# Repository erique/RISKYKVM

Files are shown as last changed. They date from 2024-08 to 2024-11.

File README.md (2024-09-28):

# RISKYKVM
Amiga adapter targets KVMs, but can be used as USB to DB9 and Amiga Keyabord interface

Project is based on following projects:
- Mist (USB HID parser stack)
- Mouse Driver - sq7bti.
- Simon Inns smallymouse2 mouse quadrature encoding
- Amiga Keyboard handler: https://github.com/gianlucarenzi/stalker
- WCH Example projects for CH32V203

## BOM
- "C1,C2,C3,C4,C5,C6" - 100nF 0603 
- "C9" - 0.1μF 0603
- "D1,D2" - LED 0805
- "F1" - Fuse 1206 500MA
- "J1" - DB9_Plug
- "J2" - Conn_01x02
- "J3" - USB_1
- "J4" - Conn_01x08
- "R1,R3" - aprox 200OHM (based on LED used)
- "R2" - 10K
- "U1" - CH32V203C8T6
- "U2" - LM1117MP-3.3 SOT-89

## Programming
WCH-LINK programmer is needed for initial programming of bootloader (bootloader.hex), then you can program application (RISKYKVM.UPD) using FAT32 formatted USB FLash drive.
To program bootloader or standard version of firmware use MounRiver IDE.

### Programming application firmware with custom bootloader.
1. Short CLK and DIO pins togeter, and power on device. When RDY LED starts to blink few times.
2. Insert USB Flash drive with RISKYKVM.UPD file in root directory.
3. If flashing is sucessful RDY LED will start slowly flashing 10x, if process failes then RDY flash either will be off, or will start flashing quickly 100x.
4. Power off device, remove jumper or disconnect CLK and DIO pins.
5. Device is ready to use.



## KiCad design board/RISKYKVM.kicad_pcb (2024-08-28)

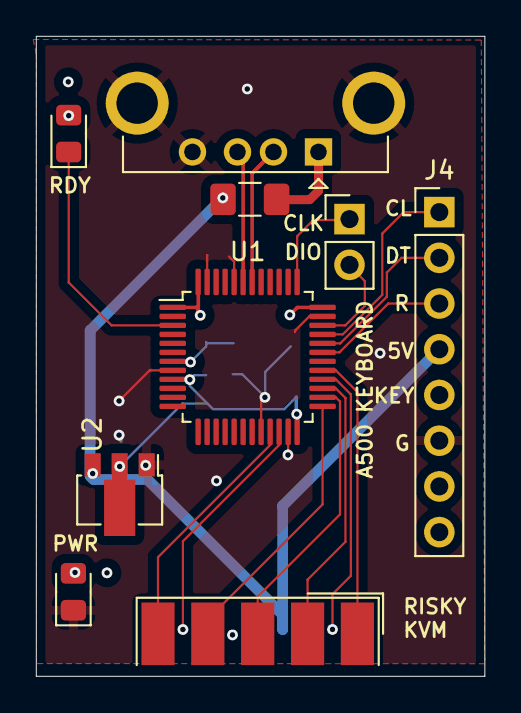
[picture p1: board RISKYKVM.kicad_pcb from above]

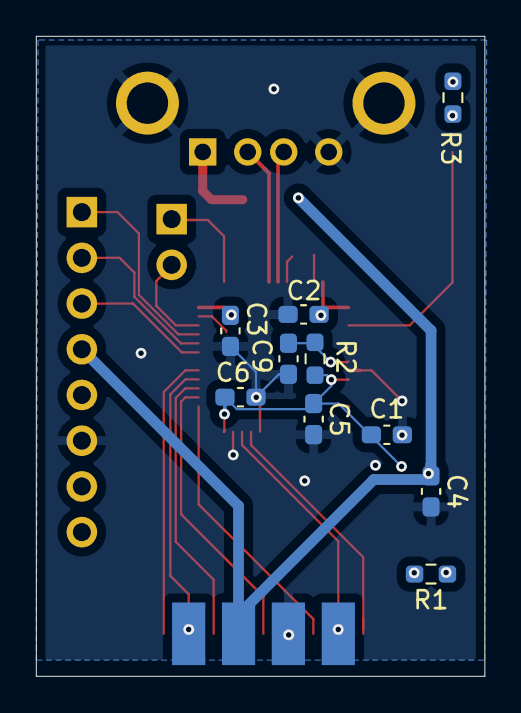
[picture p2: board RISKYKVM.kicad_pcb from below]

Board: 4 copper layers, 24.9 x 35.6 mm, 19 parts (10 on the bottom side), 22 nets.

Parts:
C1, C2, C3, C4, C5, C6: C; C_0603_1608Metric_Pad1.08x0.95mm_HandSolder
C9: 0.1μF; C_0603_1608Metric_Pad1.08x0.95mm_HandSolder
D1, D2: LED; LED_0805_2012Metric_Pad1.15x1.40mm_HandSolder
F1: Fuse; Fuse_1206_3216Metric_Pad1.42x1.75mm_HandSolder
J1: DE9_Plug; DSUB-9_Female_EdgeMount_P2.77mm
J2: Conn_01x02; PinHeader_1x02_P2.54mm_Vertical
J3: USB_1; USB_A_CONNFLY_DS1095-WNR0
J4: Conn_01x08; PinHeader_1x08_P2.54mm_Vertical
R1, R3: 2.2k; R_0603_1608Metric_Pad0.98x0.95mm_HandSolder
R2: R; R_0603_1608Metric_Pad0.98x0.95mm_HandSolder
U1: CH32V203C8T6; LQFP-48_7x7mm_P0.5mm
U2: LM1117MP-3.3; SOT-89-3

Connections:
+3.3V: C1.1, C2.1, C3.1, C5.1, C6.1, R1.2, R2.1, R3.2, U1.1 (VBAT), U1.9 (VDDA), U1.24 (VDD_VIO1), U1.36 (VDD_2), U1.48 (VDD_VIO_3), U2.2 (VO)
+5V: C4.1, F1.2, J1.7, J4.4, U2.3 (VI)
/KB_CLK: J4.1, U1.33 (PA12_USB1DP(FT))
/KB_DATA: J4.2, U1.32 (PA11_USB1DM(FT))
/KB_RESET: J4.3, U1.31 (PA10(FT))
/LED1: D2.1 (K), U1.3 (PC14_OSC32IN)
/NRST: C9.1, R2.2, U1.7 (NRST)
/PIN1: J1.1, U1.29 (PA8(FT))
/PIN2: J1.2, U1.27 (PB14(FT))
/PIN3: J1.3, U1.26 (PB13(FT))
/PIN4: J1.4, U1.25 (PB12(FT))
/PIN5: J1.5, U1.21 (PB10(FT))
/PIN6: J1.6, U1.28 (PB15(FT))
/PIN9: J1.9, U1.22 (PB11(FT))
/SWCLK: J2.1, U1.37 (PA14_SWCLK(FT))
/SWDIO: J2.2, U1.34 (PA13_SWDIO(FT))
/USB_DM: J3.2 (D-), U1.42 (PB6_USB2DM(FT))
/USB_DP: J3.3 (D+), U1.43 (PB7_USB2DP(FT))
GND: C1.2, C2.2, C3.2, C4.2, C5.2, C6.2, C9.2, D1.1 (K), J1.8, J3.4 (GND), J3.5 (Shield), J4.6, U1.8 (VSSA), U1.20 (PB2_BOOT1(FT)), U1.23 (VSS1), U1.35 (VSS_2), U1.44 (BOOT0), U1.47 (VSS_3), U2.1 (GND)
unnamed: D1.2 (A), R1.1
unnamed: D2.2 (A), R3.1
unnamed: F1.1, J3.1 (VBUS)

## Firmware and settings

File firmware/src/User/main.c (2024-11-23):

#include <usb_gamepad.h>
#include <usb_mouse.h>
#include <usb_keyboard.h>
#include "usb_host_config.h"
#include "utils.h"
#include "tim.h"
#include "mouse.h"
#include "gpio.h"
#include "keyboard.h"
#include "gamepad.h"



void IWDG_Feed_Init(u16 prer, u16 rlr)
{
    IWDG_WriteAccessCmd(IWDG_WriteAccess_Enable);
    IWDG_SetPrescaler(prer);
    IWDG_SetReload(rlr);
    IWDG_ReloadCounter();
    IWDG_Enable();
}



int main( void )
{
   // USART_Printf_Init( 115200 );
    DUG_PRINTF( "SystemClk:%d\r\n", SystemCoreClock );
    Delay_Init( );
    TIM3_Init( 9, SystemCoreClock / 10000 - 1 );

#if DEF_USBFS_PORT_EN
    USBFS_RCC_Init( );
    USBFS_Host_Init( ENABLE );
    memset( &RootHubDev.bStatus, 0, sizeof( ROOT_HUB_DEVICE ) );
    memset( &HostCtl[ DEF_USBFS_PORT_INDEX * DEF_ONE_USB_SUP_DEV_TOTAL ].InterfaceNum, 0, DEF_ONE_USB_SUP_DEV_TOTAL * sizeof( HOST_CTL ) );
#endif
    TIM1_Init();
    TIM2_Init();
    TIM4_Init();
    GPIO_Config();
    InitMouse();
    IWDG_Feed_Init( IWDG_Prescaler_32, 4000 );

	while (1) {
	    IWDG_ReloadCounter();
		USBH_MainDeal();
		//Handle HID Device
		if (RootHubDev.bType == USB_DEV_CLASS_HID) {

			for (int itf = 0; itf < DEF_INTERFACE_NUM_MAX; itf++) {
				//Handle mouse
				if (HostCtl[0].Interface[itf].HIDRptDesc.type
						== REPORT_TYPE_MOUSE) {
				    HID_MOUSE_Data *mousemap = USB_GetMouseInfo(
							&HostCtl[0].Interface[itf]);
					ProcessMouse(mousemap);
				}

				//Handle gamepad
				if (HostCtl[0].Interface[itf].HIDRptDesc.type
						== REPORT_TYPE_JOYSTICK) {

		HID_gamepad_Info_TypeDef *gamepad = GetGamepadInfo(
							&HostCtl[0].Interface[itf]);
						ProcessGamepad(gamepad);
				}

				// Handle Keyboard
				if (HostCtl[0].Interface[itf].HIDRptDesc.type
						== REPORT_TYPE_KEYBOARD) {
					//HID_KEYBD_Info_TypeDef *USBH_HID_GetKeybdInfo(Interface *Itf)
				    HID_Keyboard_Data *kbd = USBH_HID_GetKeyboardInfo(
							&HostCtl[0].Interface[itf]);

					amikb_process(kbd);

				}

			}
		}

		//Handle HUB Device

		if (RootHubDev.bType == USB_DEV_CLASS_HUB) {

			//Iterate over all devices
			for (uint8_t device = 1; device < 5; device++)
			{
				//Iterate over all interfaces
				for (int itf = 0; itf < DEF_INTERFACE_NUM_MAX; itf++) {
					//Handle mouse
					if (HostCtl[device].Interface[itf].HIDRptDesc.type
							== REPORT_TYPE_MOUSE) {
					    HID_MOUSE_Data *mousemap = USB_GetMouseInfo(
								&HostCtl[device].Interface[itf]);
							ProcessMouse(mousemap);

					}

					//Handle gamepad
					if (HostCtl[device].Interface[itf].HIDRptDesc.type
							== REPORT_TYPE_JOYSTICK) {

			HID_gamepad_Info_TypeDef *gamepad = GetGamepadInfo(
								&HostCtl[device].Interface[itf]);
							ProcessGamepad(gamepad);
					}

					// Handle Keyboard
					if (HostCtl[device].Interface[itf].HIDRptDesc.type
							== REPORT_TYPE_KEYBOARD) {
					    HID_Keyboard_Data *kbd = USBH_HID_GetKeyboardInfo(
								&HostCtl[device].Interface[itf]);
							amikb_process(kbd);

					}

				}
			}



			}

		}

	}

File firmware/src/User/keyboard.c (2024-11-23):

#include <string.h>
#include <stdlib.h>
#include <stdbool.h>
#include "keyboard.h"
#include "usb_keyboard.h"
#include "gpio.h"


uint8_t charToSend;
uint8_t processFlag = 1;
uint8_t i = 0;



static HID_Keyboard_Data prevkeycode = {
		.lctrl          = 0,
		.lshift         = 0,
		.lalt           = 0,
		.lgui           = 0,
		.rctrl          = 0,
		.rshift         = 0,
		.ralt           = 0,
		.rgui           = 0,
		.keys[0]        = 0,
		.keys[1]        = 0,
		.keys[2]        = 0,
		.keys[3]        = 0,
		.keys[4]        = 0,
		.keys[5]        = 0,
};


#define KEY_BUFF_SIZE							50




#define KEY_NONE                               0x00
#define KEY_ERRORROLLOVER                      0x01
#define KEY_POSTFAIL                           0x02
#define KEY_ERRORUNDEFINED                     0x03
#define KEY_A                                  0x04
#define KEY_B                                  0x05
#define KEY_C                                  0x06
#define KEY_D                                  0x07
#define KEY_E                                  0x08
#define KEY_F                                  0x09
#define KEY_G                                  0x0A
#define KEY_H                                  0x0B
#define KEY_I                                  0x0C
#define KEY_J                                  0x0D
#define KEY_K                                  0x0E
#define KEY_L                                  0x0F
#define KEY_M                                  0x10
#define KEY_N                                  0x11
#define KEY_O                                  0x12
#define KEY_P                                  0x13
#define KEY_Q                                  0x14
#define KEY_R                                  0x15
#define KEY_S                                  0x16
#define KEY_T                                  0x17
#define KEY_U                                  0x18
#define KEY_V                                  0x19
#define KEY_W                                  0x1A
#define KEY_X                                  0x1B
#define KEY_Y                                  0x1C
#define KEY_Z                                  0x1D
#define KEY_1_EXCLAMATION_MARK                 0x1E
#define KEY_2_AT                               0x1F
#define KEY_3_NUMBER_SIGN                      0x20
#define KEY_4_DOLLAR                           0x21
#define KEY_5_PERCENT                          0x22
#define KEY_6_CARET                            0x23
#define KEY_7_AMPERSAND                        0x24
#define KEY_8_ASTERISK                         0x25
#define KEY_9_OPARENTHESIS                     0x26
#define KEY_0_CPARENTHESIS                     0x27
#define KEY_ENTER                              0x28
#define KEY_ESCAPE                             0x29
#define KEY_BACKSPACE                          0x2A
#define KEY_TAB                                0x2B
#define KEY_SPACEBAR                           0x2C
#define KEY_MINUS_UNDERSCORE                   0x2D
#define KEY_EQUAL_PLUS                         0x2E
#define KEY_OBRACKET_AND_OBRACE                0x2F
#define KEY_CBRACKET_AND_CBRACE                0x30
#define KEY_BACKSLASH_VERTICAL_BAR             0x31
#define KEY_NONUS_NUMBER_SIGN_TILDE            0x32
#define KEY_SEMICOLON_COLON                    0x33
#define KEY_SINGLE_AND_DOUBLE_QUOTE            0x34
#define KEY_GRAVE_ACCENT_AND_TILDE             0x35
#define KEY_COMMA_AND_LESS                     0x36
#define KEY_DOT_GREATER                        0x37
#define KEY_SLASH_QUESTION                     0x38
#define KEY_CAPS_LOCK                          0x39
#define KEY_F1                                 0x3A
#define KEY_F2                                 0x3B
#define KEY_F3                                 0x3C
#define KEY_F4                                 0x3D
#define KEY_F5                                 0x3E
#define KEY_F6                                 0x3F
#define KEY_F7                                 0x40
#define KEY_F8                                 0x41
#define KEY_F9                                 0x42
#define KEY_F10                                0x43
#define KEY_F11                                0x44
#define KEY_F12                                0x45
#define KEY_PRINTSCREEN                        0x46
#define KEY_SCROLL_LOCK                        0x47
#define KEY_PAUSE                              0x48
#define KEY_INSERT                             0x49
#define KEY_HOME                               0x4A
#define KEY_PAGEUP                             0x4B
#define KEY_DELETE                             0x4C
#define KEY_END1                               0x4D
#define KEY_PAGEDOWN                           0x4E
#define KEY_RIGHTARROW                         0x4F
#define KEY_LEFTARROW                          0x50
#define KEY_DOWNARROW                          0x51
#define KEY_UPARROW                            0x52
#define KEY_KEYPAD_NUM_LOCK_AND_CLEAR          0x53
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

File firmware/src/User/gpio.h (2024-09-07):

#ifndef __GPIO_H
#define __GPIO_H

#include "ch32v20x_gpio.h"
#include "ch32v20x_rcc.h"

#define LED_Pin GPIO_Pin_14
#define LED_GPIO_Port GPIOC

#define RB_Pin GPIO_Pin_11
#define RB_GPIO_Port GPIOB

#define MB_Pin GPIO_Pin_10
#define MB_GPIO_Port GPIOB

#define LB_Pin GPIO_Pin_15
#define LB_GPIO_Port GPIOB

#define RHQ_Pin GPIO_Pin_12
#define RHQ_GPIO_Port GPIOB
#define LVQ_Pin GPIO_Pin_13
#define LVQ_GPIO_Port GPIOB



#define BH_Pin GPIO_Pin_14
#define BH_GPIO_Port GPIOB

#define FV_Pin GPIO_Pin_8
#define FV_GPIO_Port GPIOA

#define KBD_DATA_GPIO_Port GPIOA
#define KBD_DATA_Pin GPIO_Pin_11

#define KBD_CLOCK_GPIO_Port GPIOA
#define KBD_CLOCK_Pin GPIO_Pin_12

#define KB_RESET_GPIO_Port GPIOA
#define KB_RESET_GPIO_Pin GPIO_Pin_10


void GPIO_Config();


#endif

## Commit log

2024-08-11 Replace keybard library with my own one, some refactoring
    [gpio.c, gpio.h, keyboard.c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]
2024-08-25 Fix issues related to BOOT0 and BOOT1
    [RISKYKVM-B_Mask.gbr, RISKYKVM-B_Paste.gbr, RISKYKVM-B_Silkscreen.gbr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]
2024-08-25 KEY in Amiga Port missing
    [RISKYKVM-B_Mask.gbr, RISKYKVM-B_Paste.gbr, RISKYKVM-B_Silkscreen.gbr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]
2024-08-28 Upgrade project to KiCad 8 Tidy up board projecy
    [RISKYKVM.kicad_pcb, RISKYKVM.kicad_sch]
2024-09-06 Adapt firmaware to latest PCB design
2024-09-07 Some bugfixes to fix mouse movements and scroll functionality
    [gpio.c, gpio.h, mouse.c]
2024-10-21 Reset and IRQ support
    [gpio.c, keyboard.c, keyboard.h]
2024-11-23 reset fix, and watchdog, delete obj files
    [gpio.c, keyboard.c, main.c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]
2024-11-23 New keyboard combo for reset. Optimisations setup.
    [keyboard.c]
